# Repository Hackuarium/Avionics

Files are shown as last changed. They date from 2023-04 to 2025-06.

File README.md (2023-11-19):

# 9 outputs and 2 inputs

ACT4088 like in bioreactor:

Power supply

- LMR50410-Q1
- https://www.ti.com/lit/ds/symlink/lmr50410-q1.pdf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

SO-8

- https://www.diodes.com/assets/Datasheets/AP64100Q.pdf - 10 external components
- https://www.diodes.com/assets/Datasheets/AP64202Q.pdf - 7 external components
- https://www.mouser.ch/datasheet/2/389/l6982-2303627.pdf - 7 external components

SOT-89

- https://www.mouser.ch/datasheet/2/294/NJW4132_E-1917720.pdf - NJW4132

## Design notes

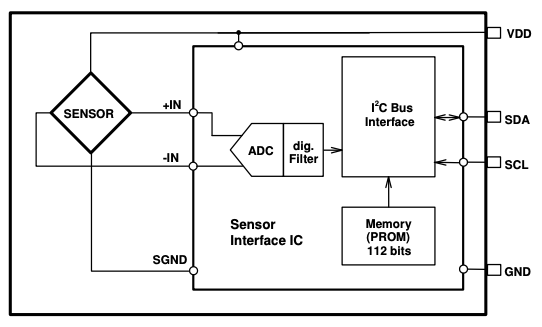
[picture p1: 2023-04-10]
images/MS5637_internal.png

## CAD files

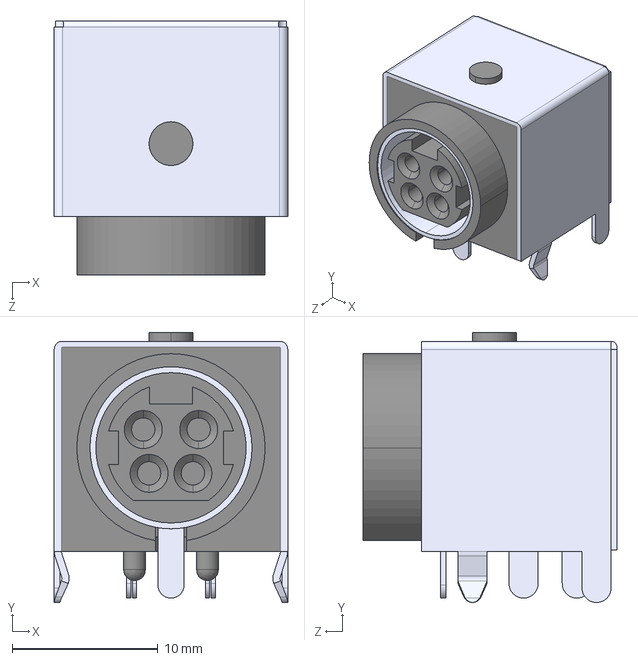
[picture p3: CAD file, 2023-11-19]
kicad-meteo/3dmodels/KPJX-4S-S.stp
16.0 x 18.5 x 17.4 mm

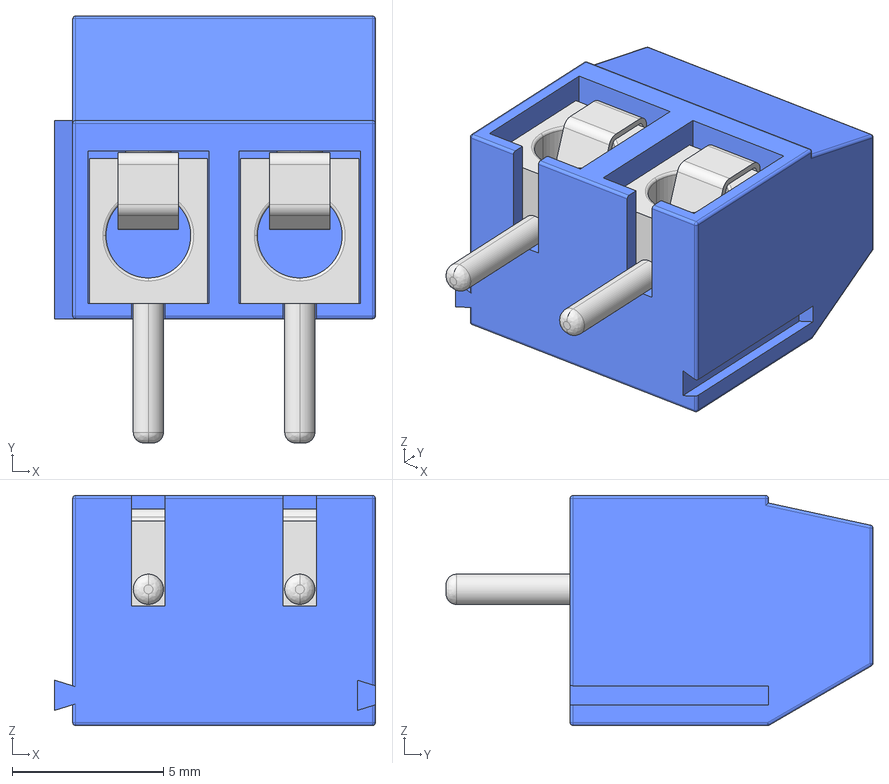
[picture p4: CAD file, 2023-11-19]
kicad-meteo/3dmodels/tb5p-2p_p5_l10_w7-6_h10.stp
10.6 x 14.1 x 7.60 mm

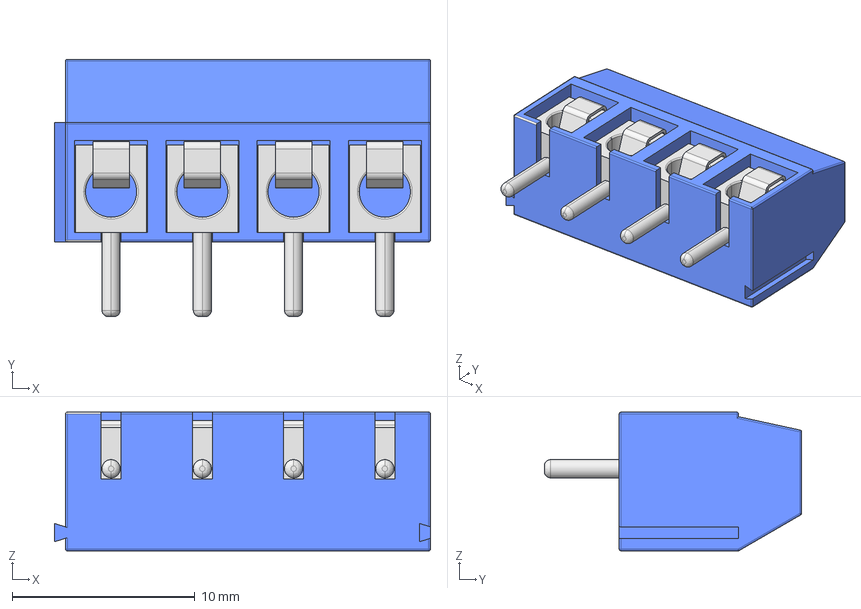
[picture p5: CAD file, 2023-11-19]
kicad-meteo/3dmodels/tb5p-4p_p5_l20_w7-6_h10.stp
20.6 x 14.1 x 7.60 mm

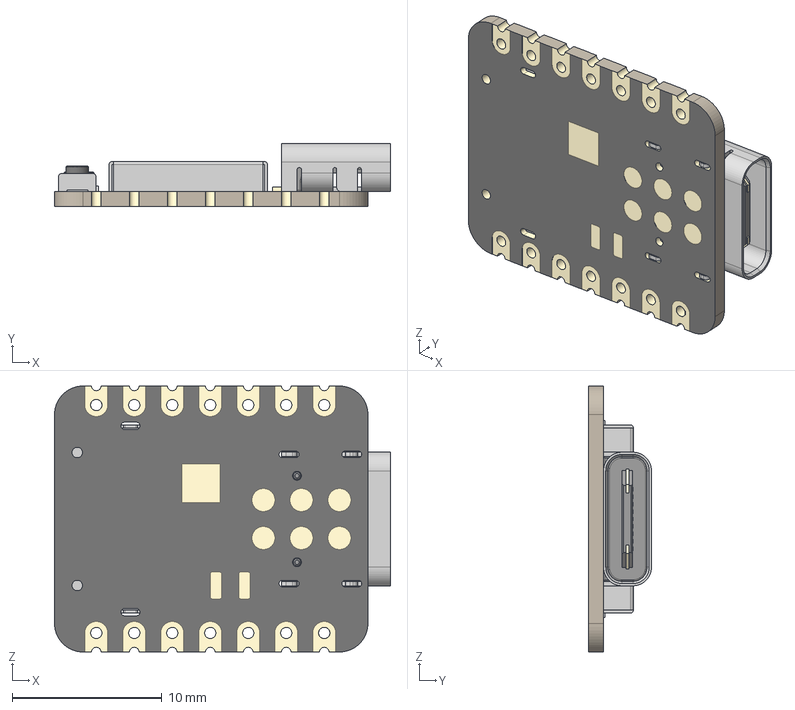
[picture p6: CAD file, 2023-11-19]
kicad-meteo/3dmodels/Seeed Studio XIAO-ESP32-C3.step
22.5 x 4.21 x 17.8 mm
BOSS-EXTRUDE14_8_
BOSS-EXTRUDE7_4_
BOSS-EXTRUDE7_3_
BOSS-EXTRUDE14_4_
BOSS-EXTRUDE14_2_
BOSS-EXTRUDE14_11_
BOSS-EXTRUDE7_7_
BOSS-EXTRUDE14_9_
BOSS-EXTRUDE14_3_
BOSS-EXTRUDE14_7_
MIRROR2
BOSS-EXTRUDE14_5_
BOSS-EXTRUDE14_12_
BOSS-EXTRUDE7_8_
BOSS-EXTRUDE7_1_
BOSS-EXTRUDE14_10_
BOSS-EXTRUDE7_9_
BOSS-EXTRUDE14_6_
BOSS-EXTRUDE14_1_
BOSS-EXTRUDE7_6_
BOSS-EXTRUDE7_2_
CUT-EXTRUDE5
BOSS-EXTRUDE7_5_
U.FL Connector v1
Button (1) x 2
Shield

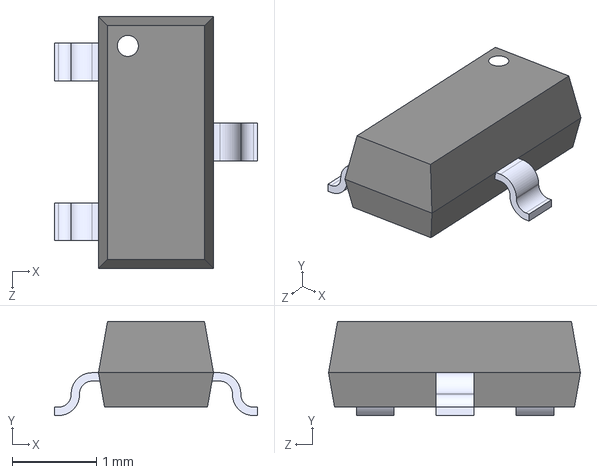
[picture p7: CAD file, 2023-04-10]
kicad-meteo/3dmodels/DMP1045U.step
2.42 x 1.12 x 3.00 mm

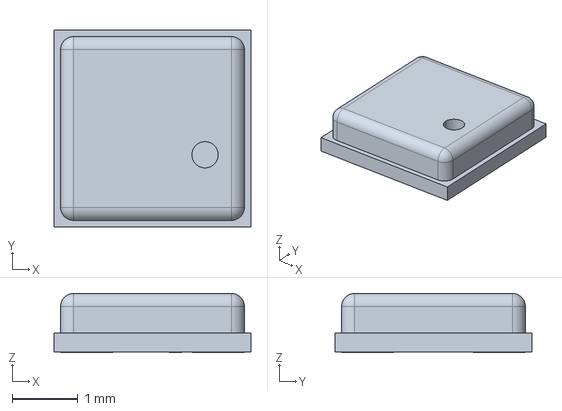
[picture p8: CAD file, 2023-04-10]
kicad-meteo/3dmodels/MS563702BA03-50.step
3.00 x 3.00 x 0.9 mm

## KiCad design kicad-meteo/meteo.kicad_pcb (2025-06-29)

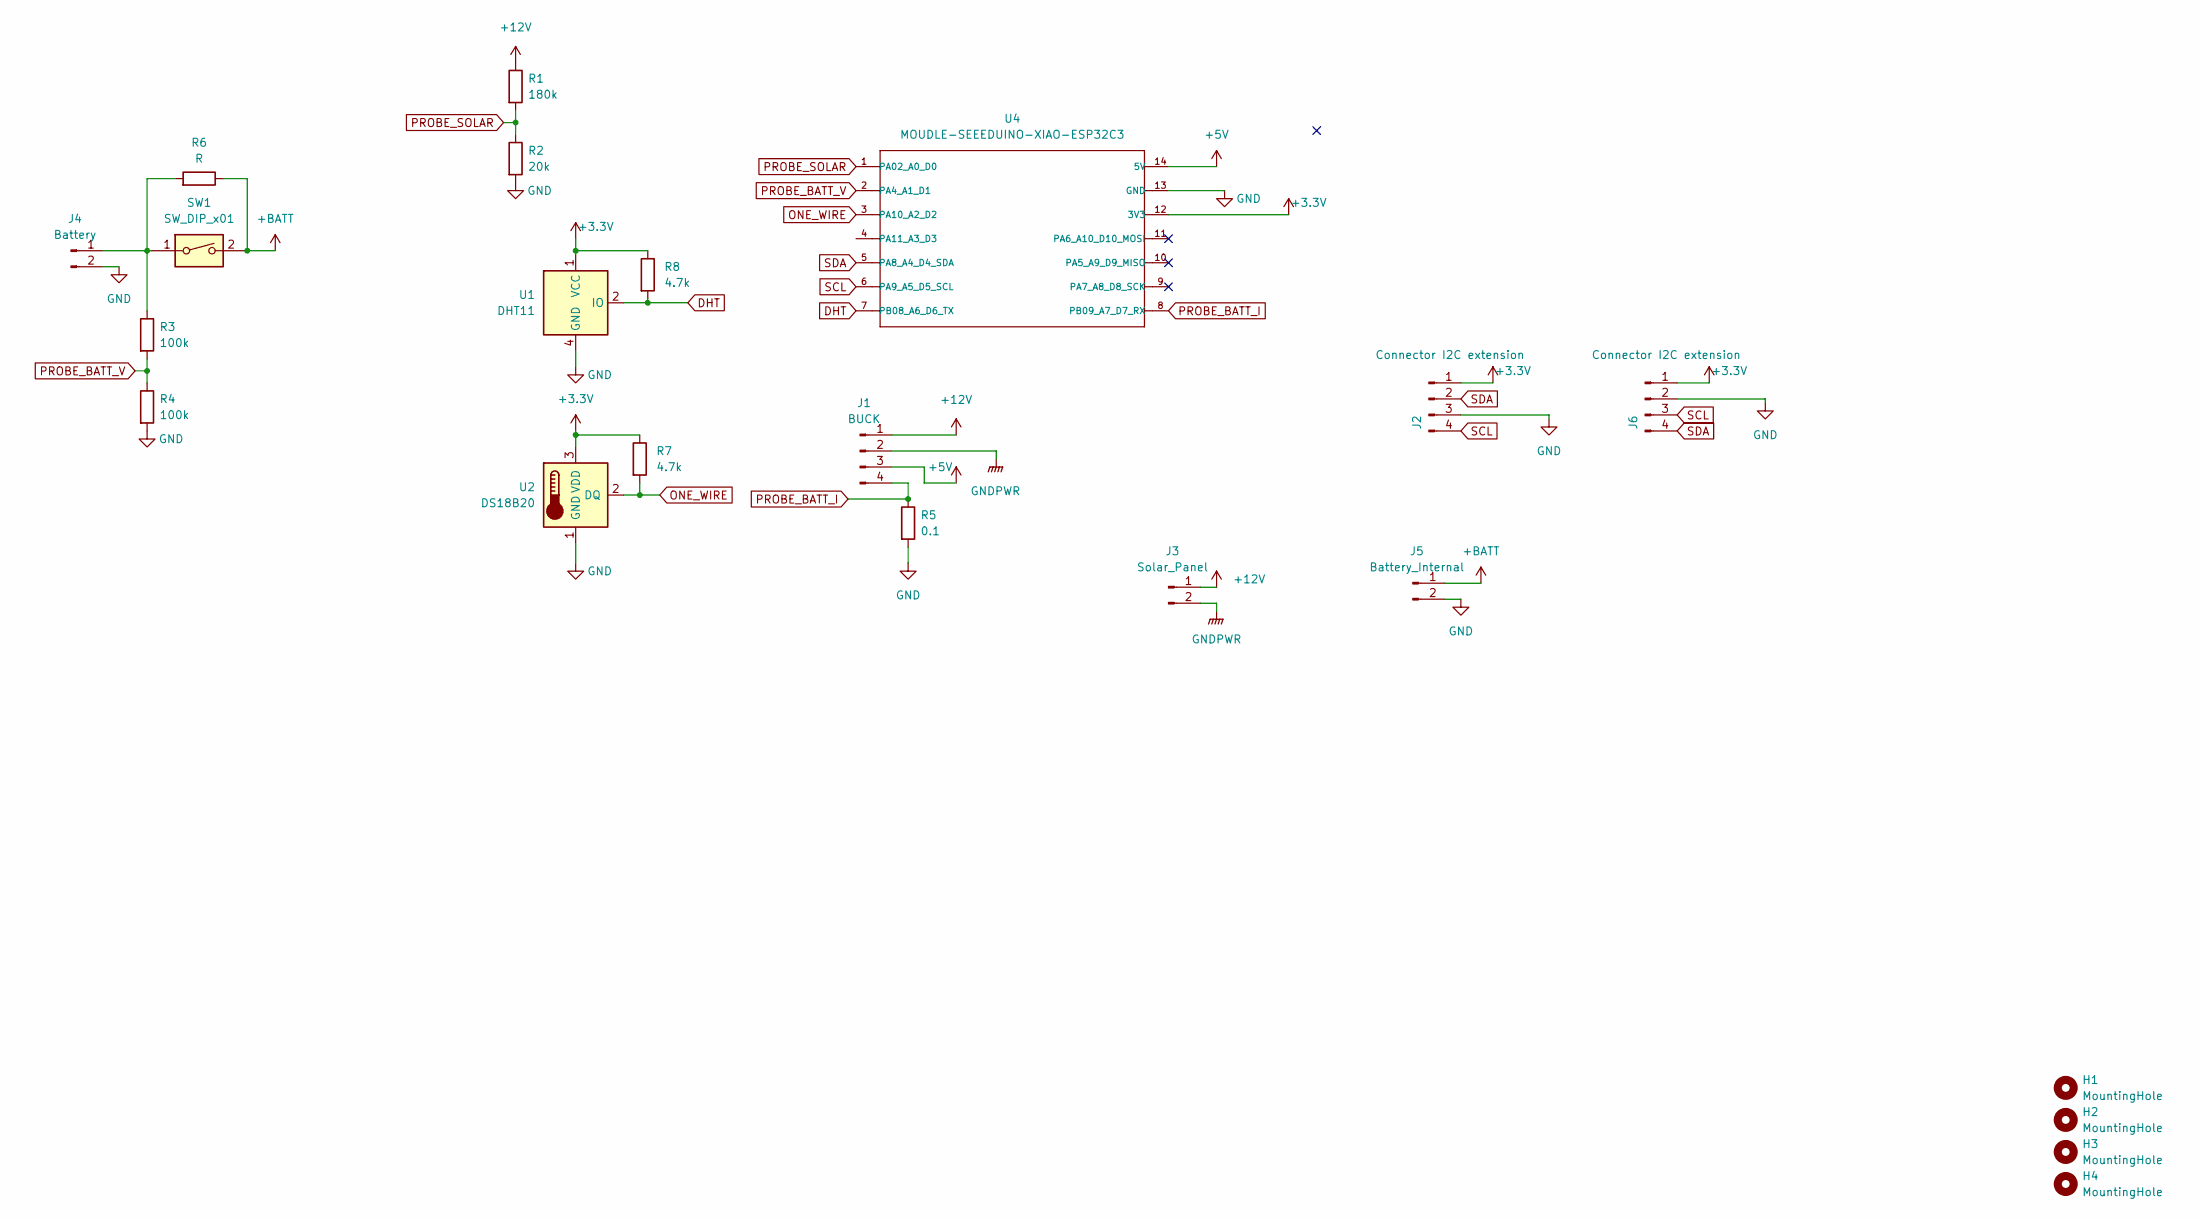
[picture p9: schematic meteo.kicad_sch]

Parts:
H1, H2, H3, H4: MountingHole; MountingHole_3.2mm_M3_ISO7380
J1: BUCK; BUCK 18x12mm
J2, J6: Connector I2C extension; PinHeader_1x04_P2.54mm_Vertical
J3: Solar_Panel; SolderWirePad_5.08x2
J4: Battery; SolderWirePad_5.08x2
J5: Battery_Internal; SolderWirePad_3x2
R1: 180k; R_1206_3216Metric_Pad1.30x1.75mm_HandSolder
R2: 20k; R_1206_3216Metric_Pad1.30x1.75mm_HandSolder
R3, R4: 100k; R_1206_3216Metric_Pad1.30x1.75mm_HandSolder
R5: 0.1; R_1206_3216Metric_Pad1.30x1.75mm_HandSolder
R6: R; R_1206_3216Metric_Pad1.30x1.75mm_HandSolder
R7, R8: 4.7k; R_1206_3216Metric_Pad1.30x1.75mm_HandSolder
SW1: SW_DIP_x01; SW_DIP_SPSTx01_Slide_9.78x4.72mm_W7.62mm_P2.54mm
U1: DHT11; Aosong_DHT11_5.5x12.0_P2.54mm
U2: DS18B20; PinHeader_1x03_P2.54mm_Vertical
U4: MOUDLE-SEEEDUINO-XIAO-ESP32C3; MOUDLE14P-SMD-2.54-21X17.8MM

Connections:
+3.3V: J2.1, J6.1, R7.1, R8.1, U1.1 (VCC), U2.3 (VDD), U4.12 (3V3)
+5V: J1.3, U4.14 (5V)
+12V: J1.1, J3.1, R1.1
+BATT: J5.1, R6.1, SW1.2
DHT: R8.2, U1.2 (IO), U4.7 (PB08_A6_D6_TX)
GND: J2.3, J4.2, J5.2, J6.2, R2.2, R4.2, R5.2, U1.4 (GND), U2.1 (GND), U4.13 (GND)
GNDPWR: J1.2, J3.2
unnamed: J4.1, R3.1, R6.2, SW1.1
ONE_WIRE: R7.2, U2.2 (DQ), U4.3 (PA10_A2_D2)
PROBE_BATT_I: J1.4, R5.1, U4.8 (PB09_A7_D7_RX)
PROBE_BATT_V: R3.2, R4.1, U4.2 (PA4_A1_D1)
PROBE_SOLAR: R1.2, R2.1, U4.1 (PA02_A0_D0)
SCL: J2.4, J6.3, U4.6 (PA9_A5_D5_SCL)
SDA: J2.2, J6.4, U4.5 (PA8_A4_D4_SDA)

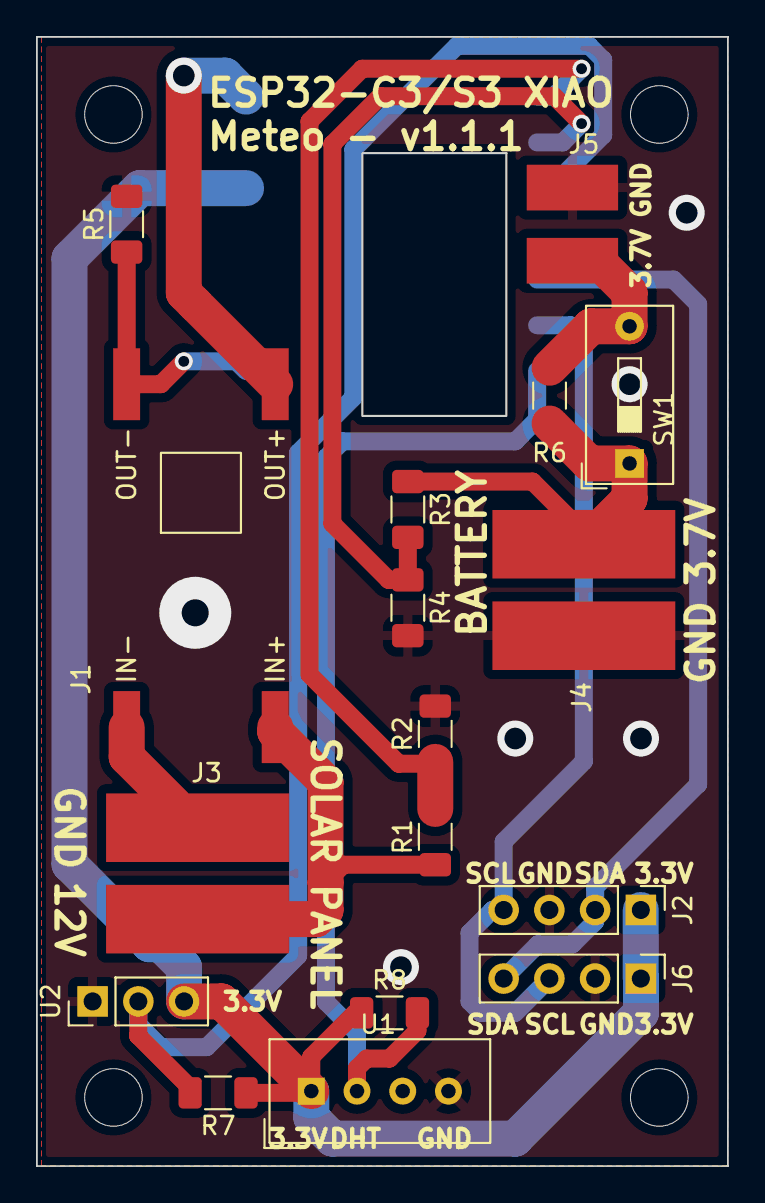
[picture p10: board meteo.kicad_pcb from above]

Board: 2 copper layers, 38.4 x 62.7 mm, 22 parts (1 on the bottom side), 14 nets.

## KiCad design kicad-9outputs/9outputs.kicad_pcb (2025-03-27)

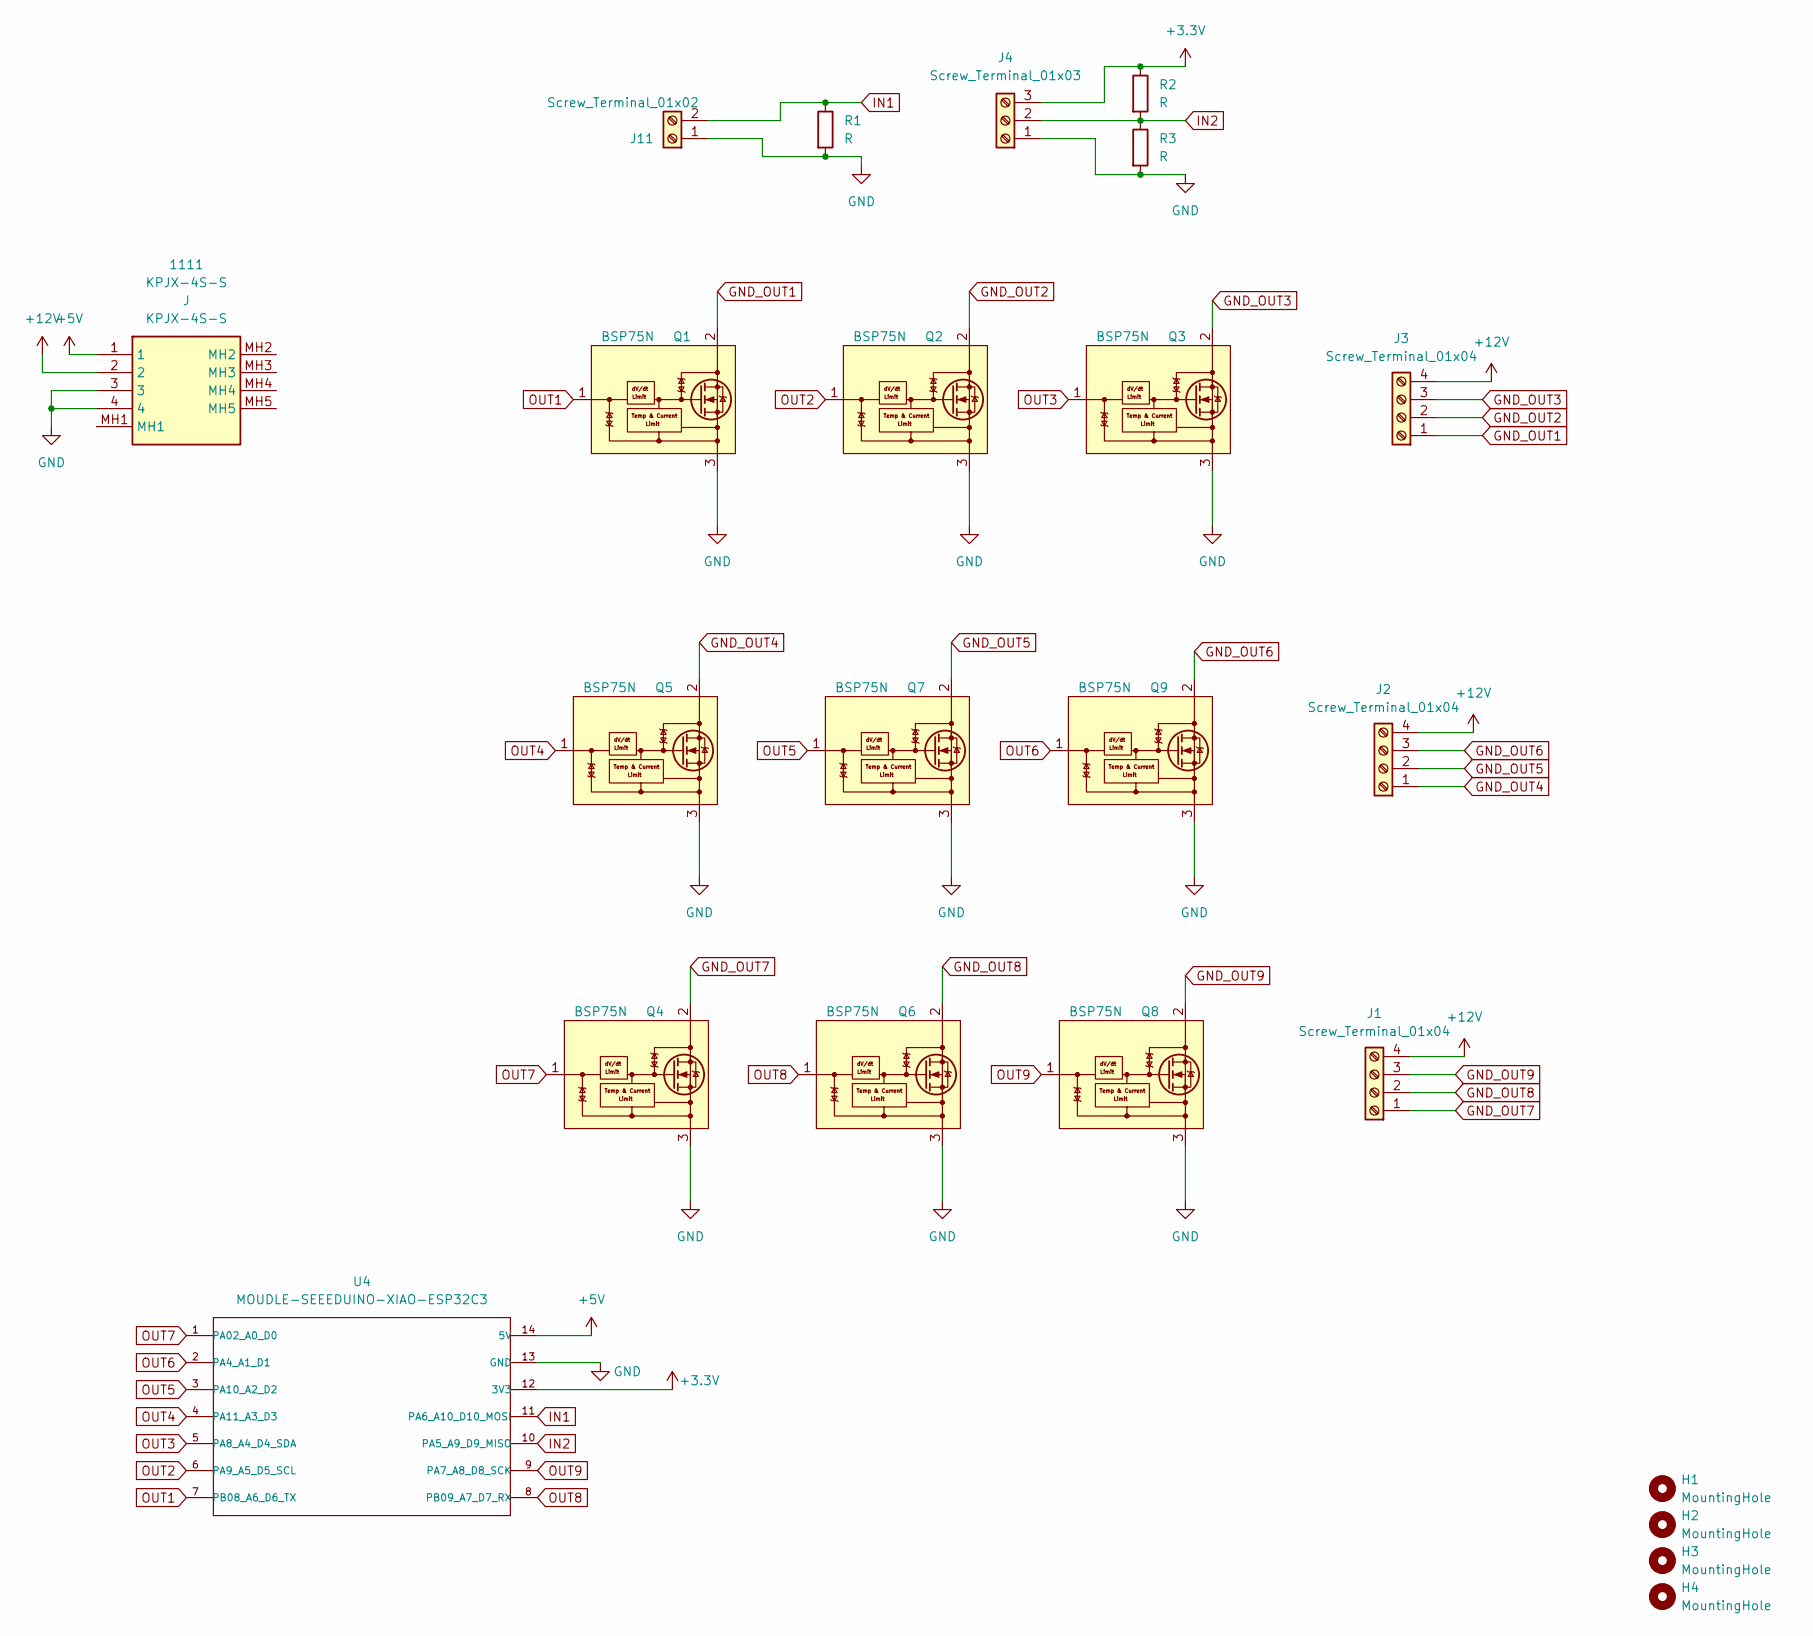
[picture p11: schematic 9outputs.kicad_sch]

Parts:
1111: KPJX-4S-S; KPJX4SS; Mouser Part Number 806-KPJX-4S-S
H1, H2, H3, H4: MountingHole; MountingHole_3.2mm_M3_ISO7380
J1, J2, J3: Screw_Terminal_01x04; TerminalBlock_MetzConnect_Type094_RT03504HBLU_1x04_P5.00mm_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
J4: Screw_Terminal_01x03; TerminalBlock_MetzConnect_Type094_RT03503HBLU_1x03_P5.00mm_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
J11: Screw_Terminal_01x02; TerminalBlock_MetzConnect_Type094_RT03502HBLU_1x02_P5.00mm_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
Q1, Q2, Q3, Q4, Q5, Q6, Q7, Q8, Q9: BSP75N; SOT-223
R1, R2, R3: R; R_1206_3216Metric_Pad1.30x1.75mm_HandSolder
U4: MOUDLE-SEEEDUINO-XIAO-ESP32C3; MOUDLE14P-SMD-2.54-21X17.8MM

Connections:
+3.3V: J4.3, R2.1, U4.12 (3V3)
+5V: 1111.1, U4.14 (5V)
+12V: 1111.2, J1.4, J2.4, J3.4
GND: 1111.3, 1111.4, J4.1, J11.1, Q1.3 (S), Q1.4 (S), Q2.3 (S), Q2.4 (S), Q3.3 (S), Q3.4 (S), Q4.3 (S), Q4.4 (S), Q5.3 (S), Q5.4 (S), Q6.3 (S), Q6.4 (S), Q7.3 (S), Q7.4 (S), Q8.3 (S), Q8.4 (S), Q9.3 (S), Q9.4 (S), R1.2, R3.2, U4.13 (GND)
GND_OUT1: J3.1, Q1.2 (D)
GND_OUT2: J3.2, Q2.2 (D)
GND_OUT3: J3.3, Q3.2 (D)
GND_OUT4: J2.1, Q5.2 (D)
GND_OUT5: J2.2, Q7.2 (D)
GND_OUT6: J2.3, Q9.2 (D)
GND_OUT7: J1.1, Q4.2 (D)
GND_OUT8: J1.2, Q6.2 (D)
GND_OUT9: J1.3, Q8.2 (D)
IN1: J11.2, R1.1, U4.11 (PA6_A10_D10_MOSI)
IN2: J4.2, R2.2, R3.1, U4.10 (PA5_A9_D9_MISO)
OUT1: Q1.1 (G), U4.7 (PB08_A6_D6_TX)
OUT2: Q2.1 (G), U4.6 (PA9_A5_D5_SCL)
OUT3: Q3.1 (G), U4.5 (PA8_A4_D4_SDA)
OUT4: Q5.1 (G), U4.4 (PA11_A3_D3)
OUT5: Q7.1 (G), U4.3 (PA10_A2_D2)
OUT6: Q9.1 (G), U4.2 (PA4_A1_D1)
OUT7: Q4.1 (G), U4.1 (PA02_A0_D0)
OUT8: Q6.1 (G), U4.8 (PB09_A7_D7_RX)
OUT9: Q8.1 (G), U4.9 (PA7_A8_D8_SCK)

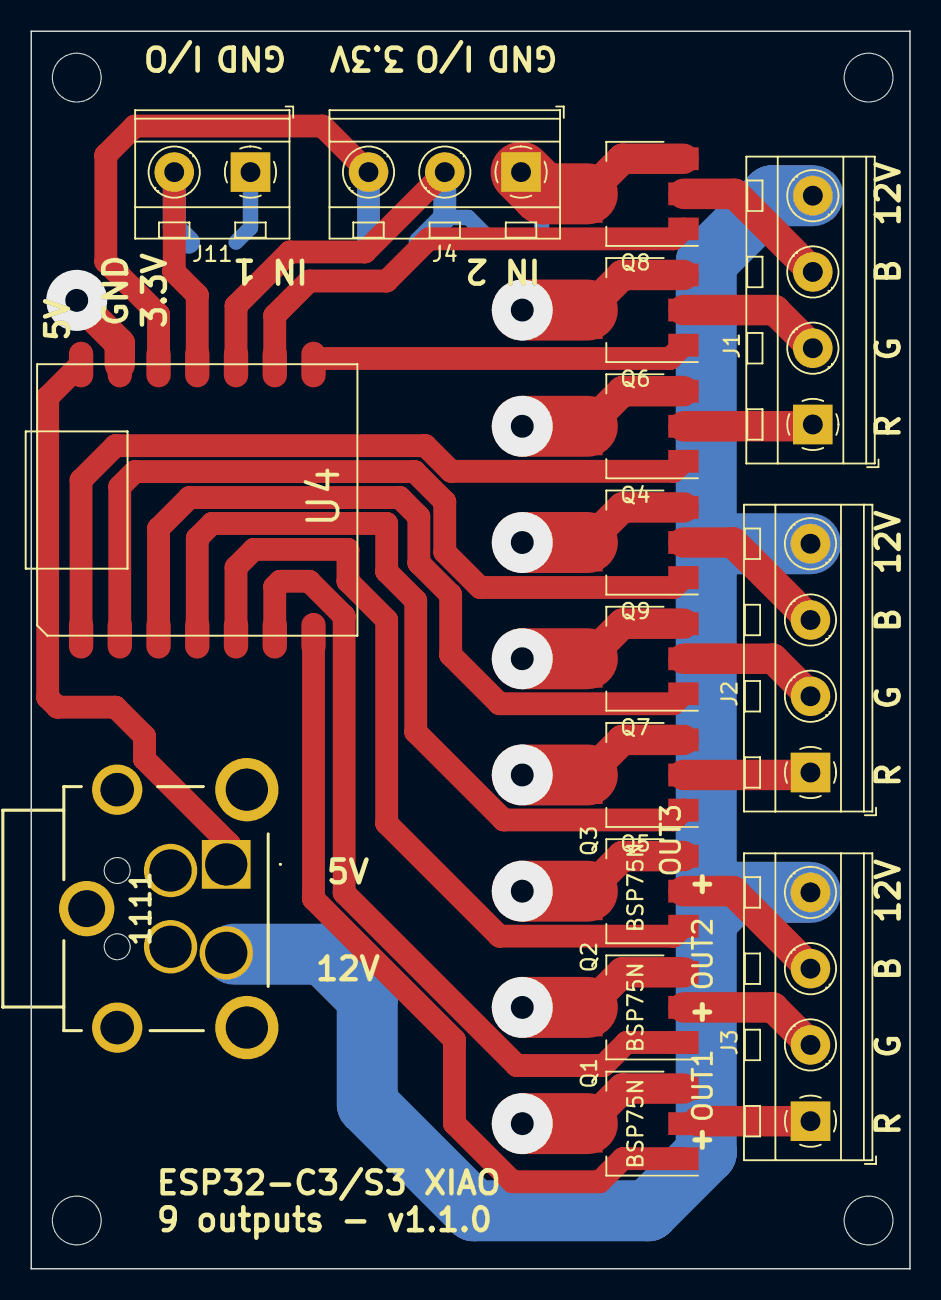
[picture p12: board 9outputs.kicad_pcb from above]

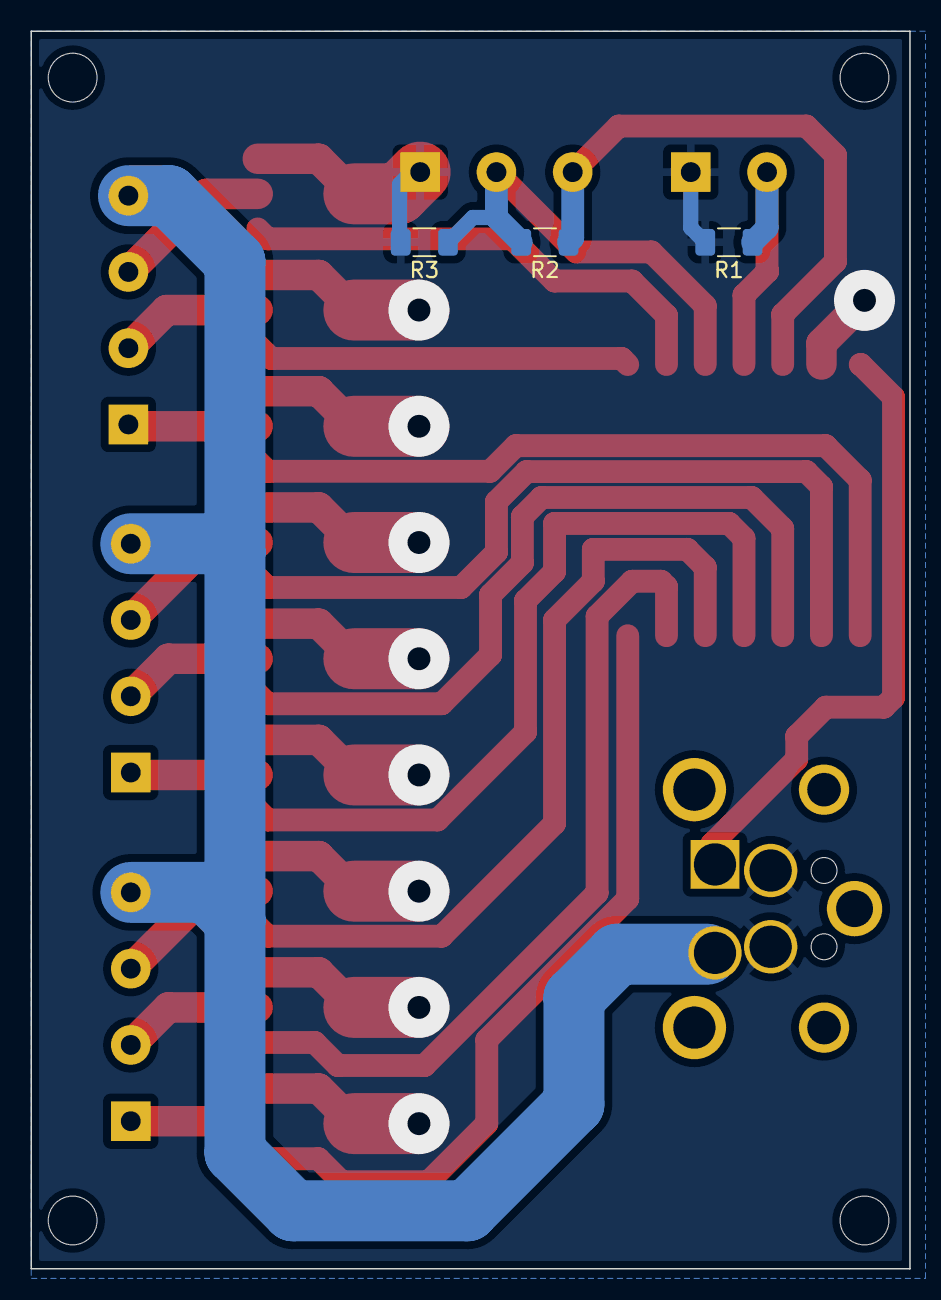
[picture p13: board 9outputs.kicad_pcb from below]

Board: 2 copper layers, 57.6 x 81.1 mm, 23 parts (3 on the bottom side), 24 nets.

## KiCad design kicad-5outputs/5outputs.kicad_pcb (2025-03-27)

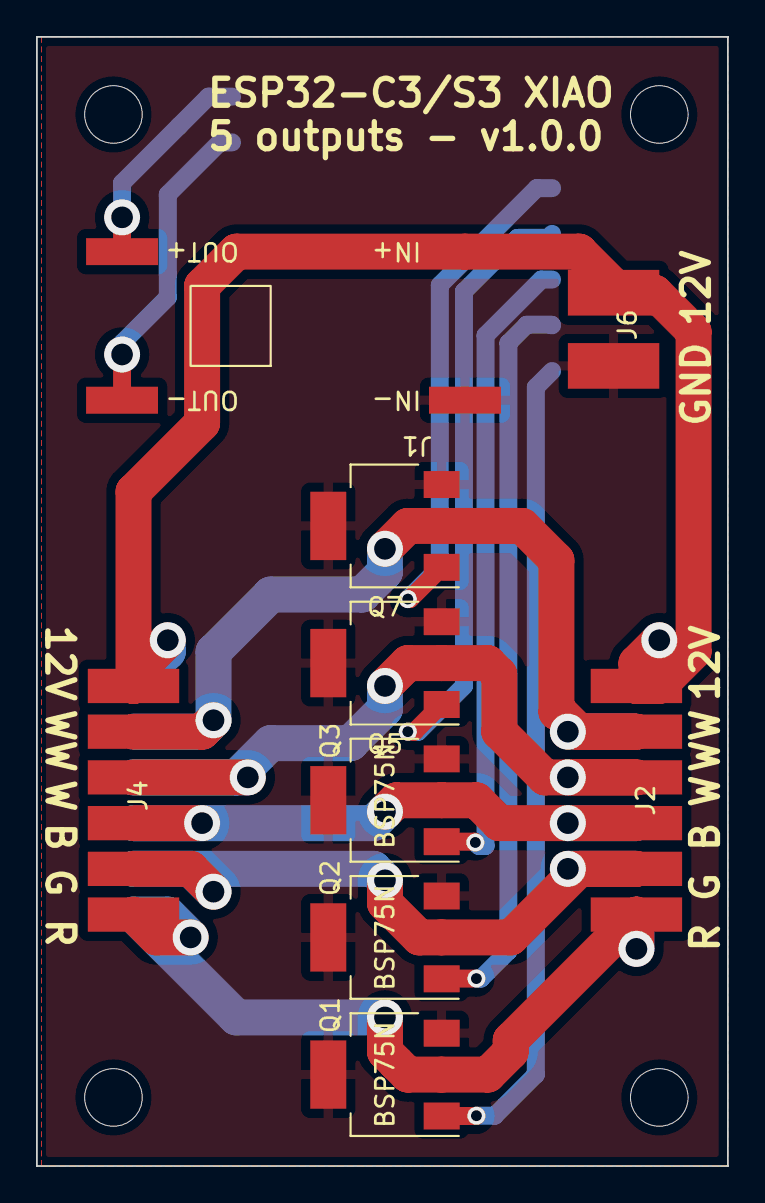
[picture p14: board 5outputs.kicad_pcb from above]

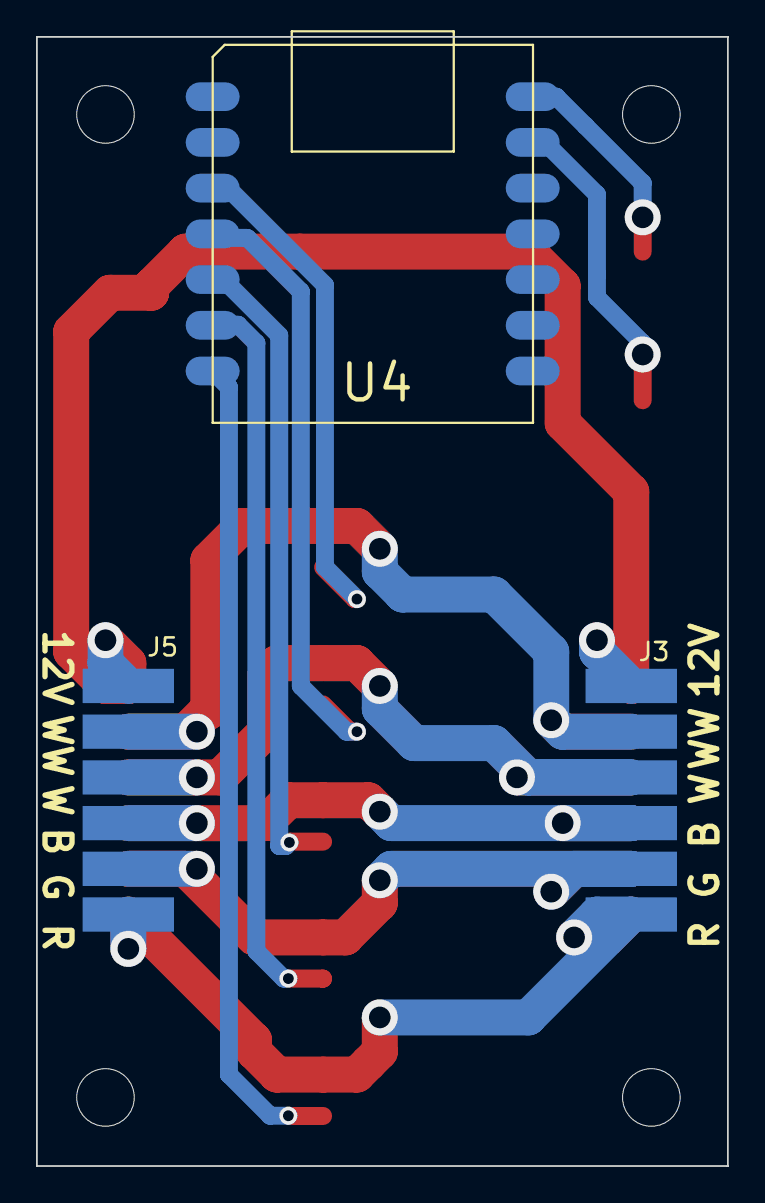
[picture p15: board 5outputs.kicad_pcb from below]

Board: 2 copper layers, 38.4 x 62.7 mm, 16 parts (3 on the bottom side), 14 nets.

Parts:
H1, H2, H3, H4: MountingHole; MountingHole_3.2mm_M3_ISO7380
J1: Conn_01x04_Male; BUCK 18x12mm
J2, J3, J4, J5: Conn_01x06_Male; SolderWirePad_2.54x6
J6: Conn_01x02_Male; SolderWirePad_3x2
Q1, Q2, Q3, Q5, Q7: BSP75N; SOT-223
U4: MOUDLE-SEEEDUINO-XIAO-ESP32C3; MOUDLE14P-SMD-2.54-21X17.8MM

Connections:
+5V: J1.3, U4.14 (5V)
+12V: J1.1, J2.1, J3.1, J4.1, J5.1, J6.1
GND: J1.4, U4.13 (GND)
GNDPWR: J1.2, J6.2, Q1.3 (S), Q1.4 (S), Q2.3 (S), Q2.4 (S), Q3.3 (S), Q3.4 (S), Q5.3 (S), Q5.4 (S), Q7.3 (S), Q7.4 (S)
GND_OUT1: J2.6, J3.6, J4.6, J5.6, Q1.2 (D)
GND_OUT2: J2.5, J3.5, J4.5, J5.5, Q2.2 (D)
GND_OUT3: J2.4, J3.4, J4.4, J5.4, Q3.2 (D)
GND_OUT4: J2.3, J3.3, J4.3, J5.3, Q5.2 (D)
GND_OUT5: J2.2, J3.2, J4.2, J5.2, Q7.2 (D)
OUT1: Q1.1 (G), U4.7 (PB08_A6_D6_TX)
OUT2: Q2.1 (G), U4.6 (PA9_A5_D5_SCL)
OUT3: Q3.1 (G), U4.5 (PA8_A4_D4_SDA)
OUT4: Q5.1 (G), U4.4 (PA11_A3_D3)
OUT5: Q7.1 (G), U4.3 (PA10_A2_D2)

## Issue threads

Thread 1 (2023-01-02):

Inspiration for accelerometer

lpatiny, 2023-01-02:
Found on: https://www.haoyuelectronics.com/Attachment/GY-521/GY-521-SCH.jpg

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

- Need to check if this AD0 pull down is useful
- The power supply will not be useful
- We need pull-up on I2C line somewhere (one for all the line)

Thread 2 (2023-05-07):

Digital out 21 is on on load

lpatiny, 2023-05-07:
Blink and digital out 21 (OUTPUT3) should be inverted because it is always on during reboot. Quite dangerous !

fpatiny, 2023-07-23:
The digital out 21 with be exchange with the digital out 20 (D7 / RX). OUTPUT3 will be on digital out 20. digital out will just be connected to a reference LED.

Closed 2023-07-29.

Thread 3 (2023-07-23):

Add second charging block

fpatiny, 2023-07-23:
Using the charging block of the MC necessitates the soldering of a pin under the tiny board of the ESP32C3 and then connecting it to the AV-Flow board. This process is not easy to set up, and the risk of breaking or detaching the pin is high. For this reason, adding a second charging block on the main board should be considered.

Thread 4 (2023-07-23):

Two face soldering

fpatiny, 2023-07-23:
Use both sides of the PCB for component soldering, reducing the size of the board and facilitating the routing.
How to manage the ground floor?

Closed 2023-07-29.

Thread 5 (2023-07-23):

Change the MC model to reduce size

fpatiny, 2023-07-23:
Use a different board with only an antenna (options on Mouser: https://www.mouser.ch/c/?q=ESP32C3)
Directly soldering the MC component? --> Not very practical as there are already many interesting features on the default board.

fpatiny, 2023-07-23:
Perhaps only change the mount type --> change to SMD instead of the trough holes freeing the second face of the board.

Closed 2023-07-29.

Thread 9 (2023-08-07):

Monitoring voltage

lpatiny, 2023-08-07:
We need to setup the internal reference of the ESP32-c3

It is not clear what is the[ default range of the ADC](https://docs.espressif.com/projects/esp-idf/en/v4.4/esp32c3/api-reference/peripherals/adc.html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,difference%2C%20hardware%20calibration%20is%20introduced).

And it is also not clear if[ it should be calibrated ](https://docs.espressif.com/projects/esp-idf/en/v4.4/esp32c3/api-reference/peripherals/adc.html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,difference%2C%20hardware%20calibration%20is%20introduced.)or not.

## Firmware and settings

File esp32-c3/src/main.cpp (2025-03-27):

#include "./common.h"
#include "./params.h"

SemaphoreHandle_t xSemaphoreWire = xSemaphoreCreateBinary();

void taskBlink();
void taskSerial();
void taskOutput();
void taskInput();
void taskTimer();
void taskBluetooth();
void taskOneWire();
void taskForecast();
void taskUptime();
void taskWifi();
void taskWifiAP();
void taskOTA();
void taskMDNS();
void taskInternalTemperature();
void taskWebserver();
void taskWire();

void setup() {
  xSemaphoreGive(xSemaphoreWire);
  Serial.begin(115200);  // only for debug purpose

  setParameter(PARAM_STATUS, 0);

  setupParameters();
#ifdef THR_PIXELS
  // taskPixels();
#endif
  // taskRocket();
  //  taskBMP280();
  // taskGY521();  // = MPU-6050

  taskSerial();
  //  taskServo();
  //   taskSi7021();

  taskOTA();
  // taskMDNS();  // incompatible with taskOTA
  if (false) {
    taskWifi();
  } else {
    taskWifiAP();
  }
  taskWebserver();
#ifdef THR_FORECAST
  taskForecast();
#endif

  taskOutput();
  taskInput();
  taskTimer();

  // taskMQTT();
  // taskOneWire();
  // taskNTPD();
  // taskInternalTemperature();
  // taskBatteryLevel();
  // taskUptime();
  // taskWire();
  // taskSPIFSLogger();
  // taskBluetooth();
#ifdef LED_ON_BOARD
  taskBlink();
#endif

  vTaskDelay(30 * 1000);  // waiting 30s before normal operation
}

void loop() {
  vTaskDelay(100);
}

void restart() {
  ESP.restart();
}

void deepSleep(int seconds) {
  if (seconds < 10) {
    return;
  }
  esp_sleep_enable_timer_wakeup(seconds * 1e6);
  esp_deep_sleep_start();
  setParameter(PARAM_STATUS, 0);
}

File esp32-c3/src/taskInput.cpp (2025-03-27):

#include "./common.h"
#include "./params.h"

void TaskInput(void* pvParameters) {
  pinMode(9, INPUT_PULLUP);
  pinMode(10, INPUT_PULLUP);
  while (true) {
    vTaskDelay(40);  // 25 times per seconds
    setParameter(PARAM_INPUT_1, digitalRead(10));
    setParameter(PARAM_INPUT_2, digitalRead(9));
    //   Serial.print(getParameter(PARAM_INPUT_1));
    //  Serial.print(" ");
    // Serial.println(getParameter(PARAM_INPUT_2));
  }
}

void taskInput() {
  // Now set up two tasks to run independently.
  xTaskCreatePinnedToCore(TaskInput, "TaskInput",
                          4096,  // This stack size can be checked & adjusted
                                 // by reading the Stack Highwater
                          NULL,
                          2,  // Priority, with 3 (configMAX_PRIORITIES - 1)
                              // being the highest, and 0 being the lowest.
                          NULL, 1);
}

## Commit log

2023-04-10 wip: pcb and md documentation
2023-04-10 wip: PCB rooting
    [SR23_T04_Avionics_V1-0-0.kicad_pcb]
2023-04-11 wip: working on avionics
    [SR23_T04_Avionics_V1-0-0.kicad_pcb]
2023-04-11 wip: rooting of the board completed - waiting on review
    [SR23_T04_Avionics_V1-0-0.kicad_pcb, SR23_T04_Avionics_V1-0-0.kicad_sch]
2023-04-11 t "wip: make the layers visible on the baord in Kicad"
2023-07-23 feat: Version 1.0.0 of the AV-Flow PCB
    [SR23_T04_Avionics_V1-0-0.kicad_pcb, SR23_T04_Avionics_V1-0-0.kicad_sch]
2023-07-29 wip: PCB V2
    [SR23_T04_Avionics_V1-0-0.kicad_pcb, SR23_T04_Avionics_V1-0-0.kicad_sch]
2023-07-30 feat: new board V2 dual sided
    closes: https://github.com/Hackuarium/Avionics/issues/7
    [SR23_T04_Avionics_V1-0-0-B_Cu.gbr, SR23_T04_Avionics_V1-0-0-B_Mask.gbr, SR23_T04_Avionics_V1-0-0-B_Paste.gbr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]
2023-11-19 feat: add program
    [10outputs.kicad_pcb, 10outputs.kicad_sch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]
2023-11-19 chore: remoe old files
    [DMP1045U.step, MS563702BA03-50.step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]
2025-03-27 feat: add 5 outputs
    [10outputs-B_Cu.gbr, 10outputs-B_Mask.gbr, 10outputs-B_Paste.gbr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]
2025-06-22 feat: add meteo v100
    [DMP1045U.step, KPJX-4S-S.stp, MS563702BA03-50.step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]
2025-06-29 feat(meteo): fix pin mapping and add switch, v1.1.0
    [meteo-B_Cu.gbr, meteo-B_Mask.gbr, meteo-B_Paste.gbr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]
2025-06-29 fix: add pull-up for DHT-22
    [meteo.kicad_pcb, meteo.kicad_sch]
2025-11-09 fix: correct AD pin for monitoring and ground
